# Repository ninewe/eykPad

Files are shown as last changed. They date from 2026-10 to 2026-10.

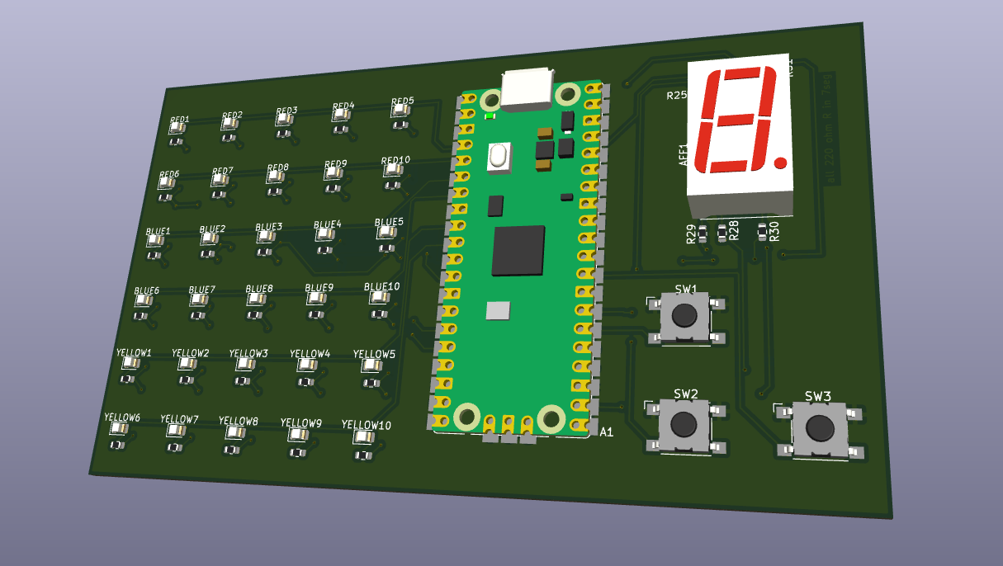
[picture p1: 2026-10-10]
board/3D view PCB.png

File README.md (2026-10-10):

# eykPad

Screenshot 2026-10-10 at 11 19 01 AM
<br><br>
<b>A multifunctional device. You can use it for:
<br><br>
   - A Timer. (Binary Mode/Regular Mode/Pomodoro Mode)<br>
   - Sequence Memorizer. (Basically Simon Says)<br>
   - Pattern Memorizer. (Memorize the pattern on the lights that show up for a split second)<br>
   - Flash Anzan. (Sequence of numbers will appear in a split second, add them up)<br>
   - Interactive Dice (Generates a Random Number.)</b>
<br><br>

For now, these are the five main functions I will focus on. 

<br>

My project mainly consists of 30 LEDS, a single-digit 7 Segment Display, and three switches. The main function for each switches are: Move right, OK, change color/boundary.

<br>

The LEDs are in a 5 by 6 matrix. I am multiplexing to save the GPIO pins. 
<br>
The top 2 rows are RED LEDs, the middle two rows are BLUE LEDs, and the last two rows are YELLOW LEDs. Since there are 10 of them each, it's easier and more efficient, since you can display numbers in base ten.

<br>

Image of the PCB in the PCB editor:<br>
Screenshot 2026-10-10 at 11 33 52 AM
<br><br>
Image of the SCHEMATIC in the SCH editor:<br>
Screenshot 2026-10-10 at 11 34 17 AM

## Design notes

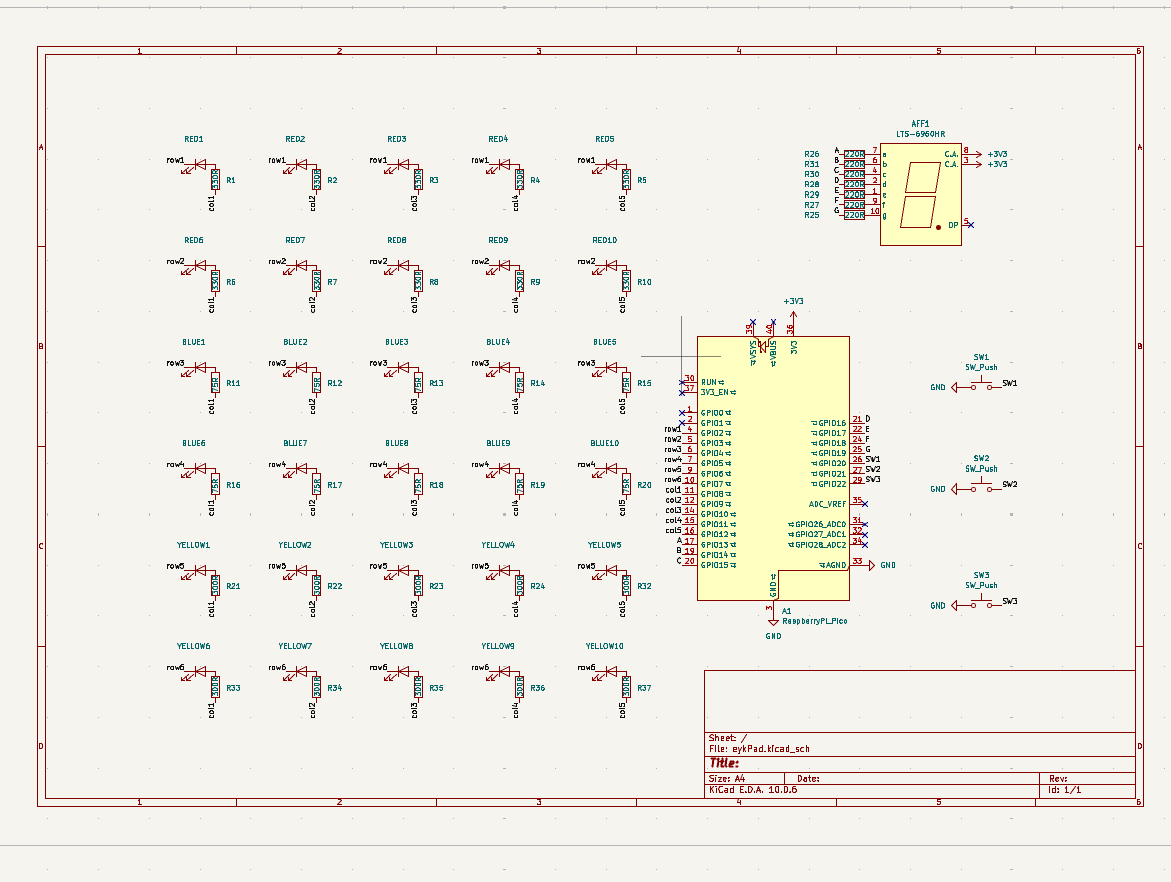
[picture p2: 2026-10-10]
board/SCHEMATIC view.png

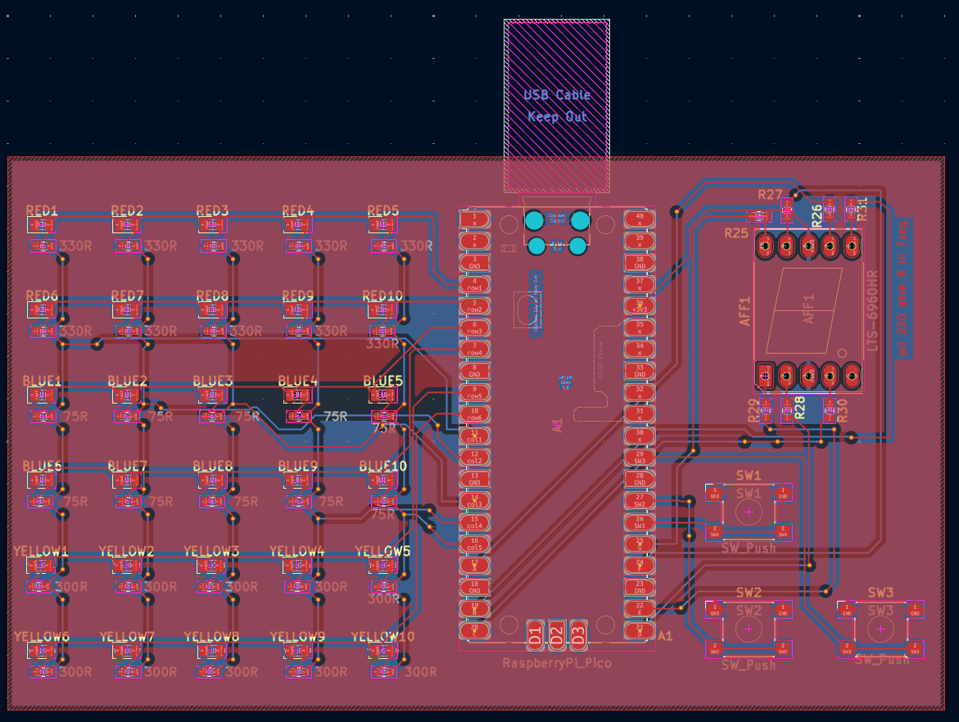
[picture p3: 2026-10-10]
board/2D view PCB.png

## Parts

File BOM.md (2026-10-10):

# eykPad – bill of materials

<!-- Generated by Half Life from project cmuusft6c0a0y01smofse3m5k. Edits here are overwritten on the next sync. -->
<!-- Generated: 2026-10-10T18:15:41.818Z -->

> [!NOTE]
> This parts list is mirrored from [Half Life](https://halflife.hackclub.com). Editing it here will not change the platform's copy, and the next sync overwrites this file.

| Week | Tier | Parts funding |
| --- | --- | --- |
| Week 1 | Tier 1 | $30.00 |

| Part | What it's for | Qty | Unit | Total | Vendor |
| --- | --- | --- | --- | --- | --- |
| [150080RS75000](https://www.digikey.com/en/products/detail/w-rth-elektronik/150080RS75000/4489918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) | Outputs of this project. (Red LED) | 12 | $0.19 | $2.28 | [DigiKey](https://www.digikey.com/en/products/detail/w-rth-elektronik/150080RS75000/4489918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) |
| [150080BS75000](https://www.digikey.com/en/products/detail/würth-elektronik/150080BS75000/4489912?s=N4IgTCBcDaIIwFYAMSAcSBCBlA7MlIAugL5A) | Outputs of this project. (Blue LED) | 12 | $0.19 | $2.28 | [DigiKey](https://www.digikey.com/en/products/detail/würth-elektronik/150080BS75000/4489912?s=N4IgTCBcDaIIwFYAMSAcSBCBlA7MlIAugL5A) |
| [150080YS75000](https://www.digikey.com/en/products/detail/würth-elektronik/150080YS75000/4489927?s=N4IgTCBcDaIIwFYAMSAcSCaBlA7MlIAugL5A) | Outputs of this project. (Yellow LED) | 12 | $0.19 | $2.28 | [DigiKey](https://www.digikey.com/en/products/detail/würth-elektronik/150080YS75000/4489927?s=N4IgTCBcDaIIwFYAMSAcSCaBlA7MlIAugL5A) |
| [SC0915](https://www.digikey.com/en/products/detail/raspberry-pi/SC0915/13624793) | The microcontroller. (Raspberry Pi Pico) | 1 | $4.59 | $4.59 | [DigiKey](https://www.digikey.com/en/products/detail/raspberry-pi/SC0915/13624793) |
| [B3FS-1000P](https://www.digikey.com/en/products/detail/aratas-formerly-omron-components/B3FS-1000P/277812) | Inputs of this project. (The buttons) | 3 | $0.75 | $2.25 | [DigiKey](https://www.digikey.com/en/products/detail/aratas-formerly-omron-components/B3FS-1000P/277812) |
| [RC0603FR-10330RL](https://www.digikey.com/en/products/detail/yageo/rc0603fr-10330rl/13694144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) | Resistors for this LED. (for RED, 330 OHMS) | 10 | $0.03 | $0.30 | [DigiKey](https://www.digikey.com/en/products/detail/yageo/rc0603fr-10330rl/13694144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) |
| [LTS-6960HR](https://www.digikey.com/en/products/detail/liteon/LTS-6960HR/3199487) | Outputs of this project. (7 segment display) | 1 | $1.82 | $1.82 | [DigiKey](https://www.digikey.com/en/products/detail/liteon/LTS-6960HR/3199487) |
| [RC0603FR-10300RL](https://www.digikey.com/en/products/detail/yageo/RC0603FR-10300RL/14008461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) | Resistors for this LED. (for YELLOW, 300 OHMS) | 10 | $0.03 | $0.30 | [DigiKey](https://www.digikey.com/en/products/detail/yageo/RC0603FR-10300RL/14008461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) |
| [RC0603FR-0775RL](https://www.digikey.com/en/products/detail/yageo/RC0603FR-0775RL/727377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) | Resistors for this LED. (for BLUE, 75 OHMS) | 10 | $0.03 | $0.30 | [DigiKey](https://www.digikey.com/en/products/detail/yageo/RC0603FR-0775RL/727377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) |
| **Parts subtotal** | — | — | — | **$16.40** | — |
| **Tax & shipping** | — | — | — | **$7.75** | — |
| **Total** | — | — | — | **$24.15** | — |

$5.85 left of the tier's funding.

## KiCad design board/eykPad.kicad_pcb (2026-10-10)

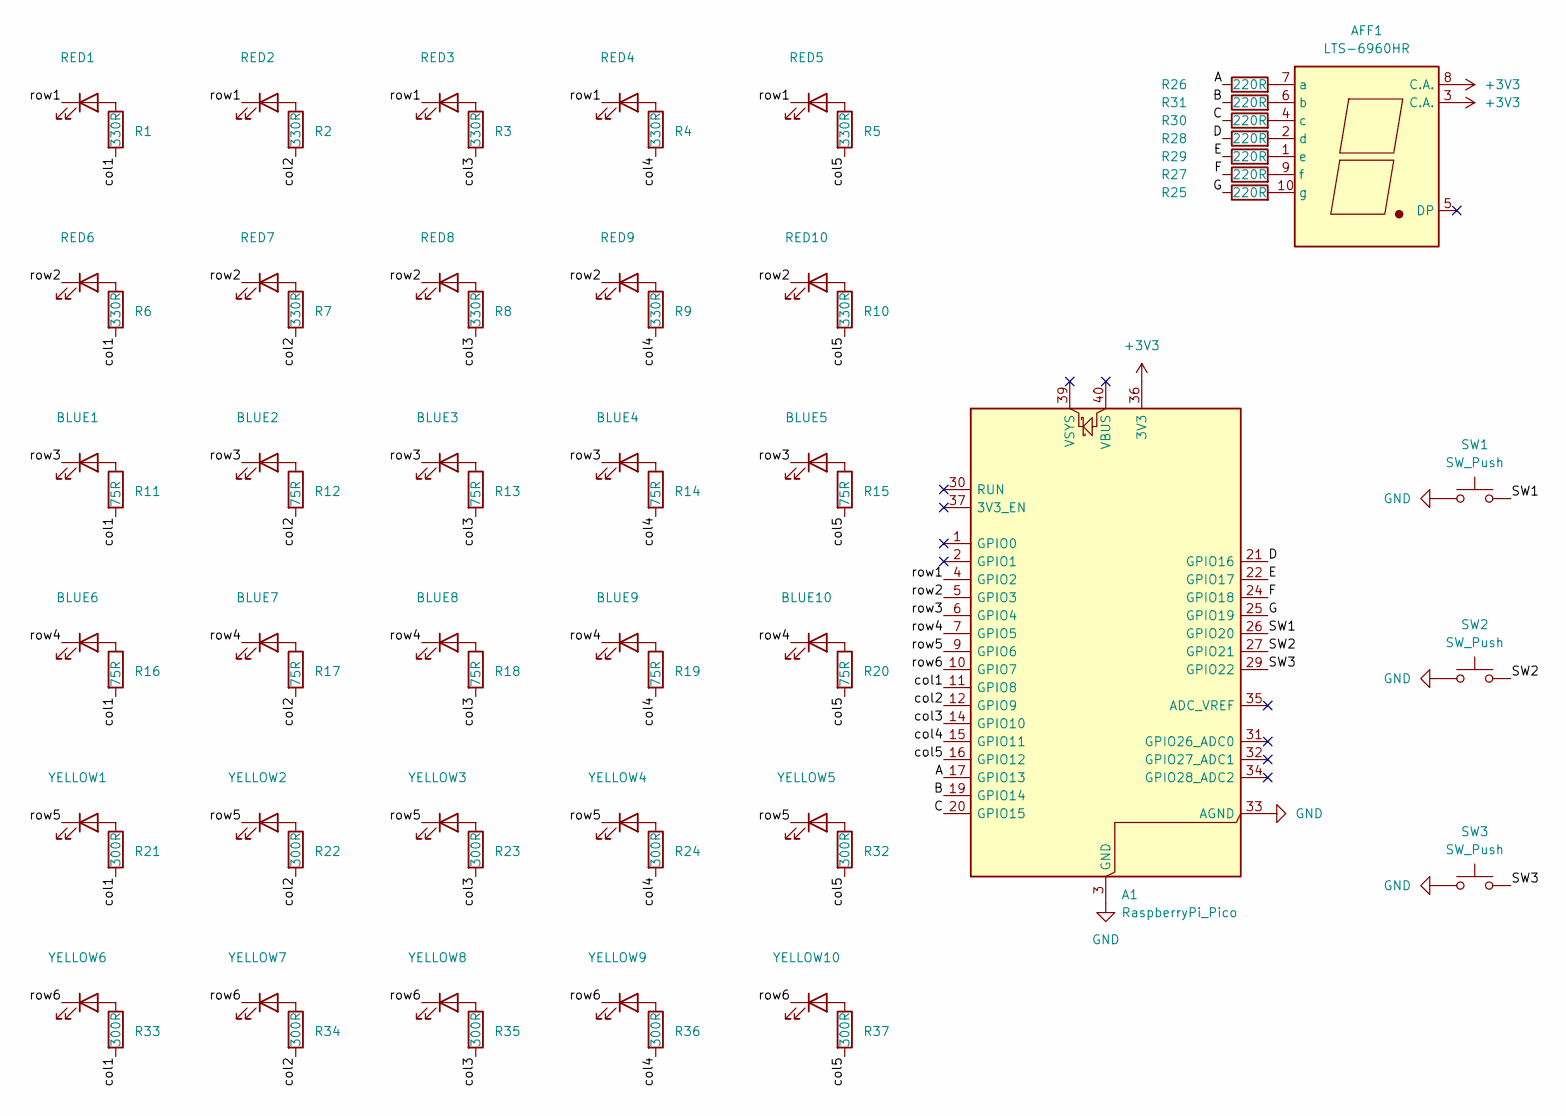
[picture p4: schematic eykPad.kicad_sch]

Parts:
A1: RaspberryPi_Pico; RaspberryPi_Pico_SMD_HandSolder
AFF1: LTS-6960HR; 7SegmentLED_LTS6760_LTS6780
BLUE1, BLUE2, BLUE3, BLUE4, BLUE5, BLUE6, BLUE7, BLUE8, BLUE9, BLUE10: 150080BS75000; LED_0805_2012Metric
R1, R2, R3, R4, R5, R6, R7, R8, R9, R10: 330R; R_0603_1608Metric
R11, R12, R13, R14, R15, R16, R17, R18, R19, R20: 75R; R_0603_1608Metric
R21, R22, R23, R24, R32, R33, R34, R35, R36, R37: 300R; R_0603_1608Metric
R25, R26, R27, R28, R29, R30, R31: 220R; R_0603_1608Metric
RED1, RED2, RED3, RED4, RED5, RED6, RED7, RED8, RED9, RED10: 150080RS75000; LED_0805_2012Metric
SW1, SW2, SW3: SW_Push; SW_SPST_Omron_B3FS-100xP
YELLOW1, YELLOW2, YELLOW3, YELLOW4, YELLOW5, YELLOW6, YELLOW7, YELLOW8, YELLOW9, YELLOW10: 150080YS75000; LED_0805_2012Metric

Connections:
+3V3: A1.36 (3V3), AFF1.3 (C.A.), AFF1.8 (C.A.)
/A: A1.17 (GPIO13), R26.1
/B: A1.19 (GPIO14), R31.1
/C: A1.20 (GPIO15), R30.1
/D: A1.21 (GPIO16), R28.1
/E: A1.22 (GPIO17), R29.1
/F: A1.24 (GPIO18), R27.1
/G: A1.25 (GPIO19), R25.1
/SW1: A1.26 (GPIO20), SW1.2
/SW2: A1.27 (GPIO21), SW2.2
/SW3: A1.29 (GPIO22), SW3.2
/col1: A1.11 (GPIO8), R1.2, R6.2, R11.2, R16.2, R21.2, R33.2
/col2: A1.12 (GPIO9), R2.2, R7.2, R12.2, R17.2, R22.2, R34.2
/col3: A1.14 (GPIO10), R3.2, R8.2, R13.2, R18.2, R23.2, R35.2
/col4: A1.15 (GPIO11), R4.2, R9.2, R14.2, R19.2, R24.2, R36.2
/col5: A1.16 (GPIO12), R5.2, R10.2, R15.2, R20.2, R32.2, R37.2
/row1: A1.4 (GPIO2), RED1.1 (K), RED2.1 (K), RED3.1 (K), RED4.1 (K), RED5.1 (K)
/row2: A1.5 (GPIO3), RED6.1 (K), RED7.1 (K), RED8.1 (K), RED9.1 (K), RED10.1 (K)
/row3: A1.6 (GPIO4), BLUE1.1 (K), BLUE2.1 (K), BLUE3.1 (K), BLUE4.1 (K), BLUE5.1 (K)
/row4: A1.7 (GPIO5), BLUE6.1 (K), BLUE7.1 (K), BLUE8.1 (K), BLUE9.1 (K), BLUE10.1 (K)
/row5: A1.9 (GPIO6), YELLOW1.1 (K), YELLOW2.1 (K), YELLOW3.1 (K), YELLOW4.1 (K), YELLOW5.1 (K)
/row6: A1.10 (GPIO7), YELLOW6.1 (K), YELLOW7.1 (K), YELLOW8.1 (K), YELLOW9.1 (K), YELLOW10.1 (K)
GND: A1.3 (GND), A1.8 (GND), A1.13 (GND), A1.18 (GND), A1.23 (GND), A1.28 (GND), A1.33 (AGND), A1.38 (GND), SW1.1, SW2.1, SW3.1
unnamed: AFF1.7 (a), R26.2
unnamed: AFF1.6 (b), R31.2
unnamed: AFF1.4 (c), R30.2
unnamed: AFF1.2 (d), R28.2
unnamed: AFF1.1 (e), R29.2
unnamed: AFF1.9 (f), R27.2
unnamed: AFF1.10 (g), R25.2
unnamed: BLUE1.2 (A), R11.1
unnamed: BLUE2.2 (A), R12.1
unnamed: BLUE3.2 (A), R13.1
unnamed: BLUE4.2 (A), R14.1
unnamed: BLUE5.2 (A), R15.1
unnamed: BLUE6.2 (A), R16.1
unnamed: BLUE7.2 (A), R17.1
unnamed: BLUE8.2 (A), R18.1
unnamed: BLUE9.2 (A), R19.1
unnamed: BLUE10.2 (A), R20.1
unnamed: R1.1, RED1.2 (A)
unnamed: R2.1, RED2.2 (A)
unnamed: R3.1, RED3.2 (A)
unnamed: R4.1, RED4.2 (A)
unnamed: R5.1, RED5.2 (A)
unnamed: R6.1, RED6.2 (A)
unnamed: R7.1, RED7.2 (A)
unnamed: R8.1, RED8.2 (A)
unnamed: R9.1, RED9.2 (A)
unnamed: R10.1, RED10.2 (A)
unnamed: R21.1, YELLOW1.2 (A)
unnamed: R22.1, YELLOW2.2 (A)
unnamed: R23.1, YELLOW3.2 (A)
unnamed: R24.1, YELLOW4.2 (A)
unnamed: R32.1, YELLOW5.2 (A)
unnamed: R33.1, YELLOW6.2 (A)
unnamed: R34.1, YELLOW7.2 (A)
unnamed: R35.1, YELLOW8.2 (A)
unnamed: R36.1, YELLOW9.2 (A)
unnamed: R37.1, YELLOW10.2 (A)

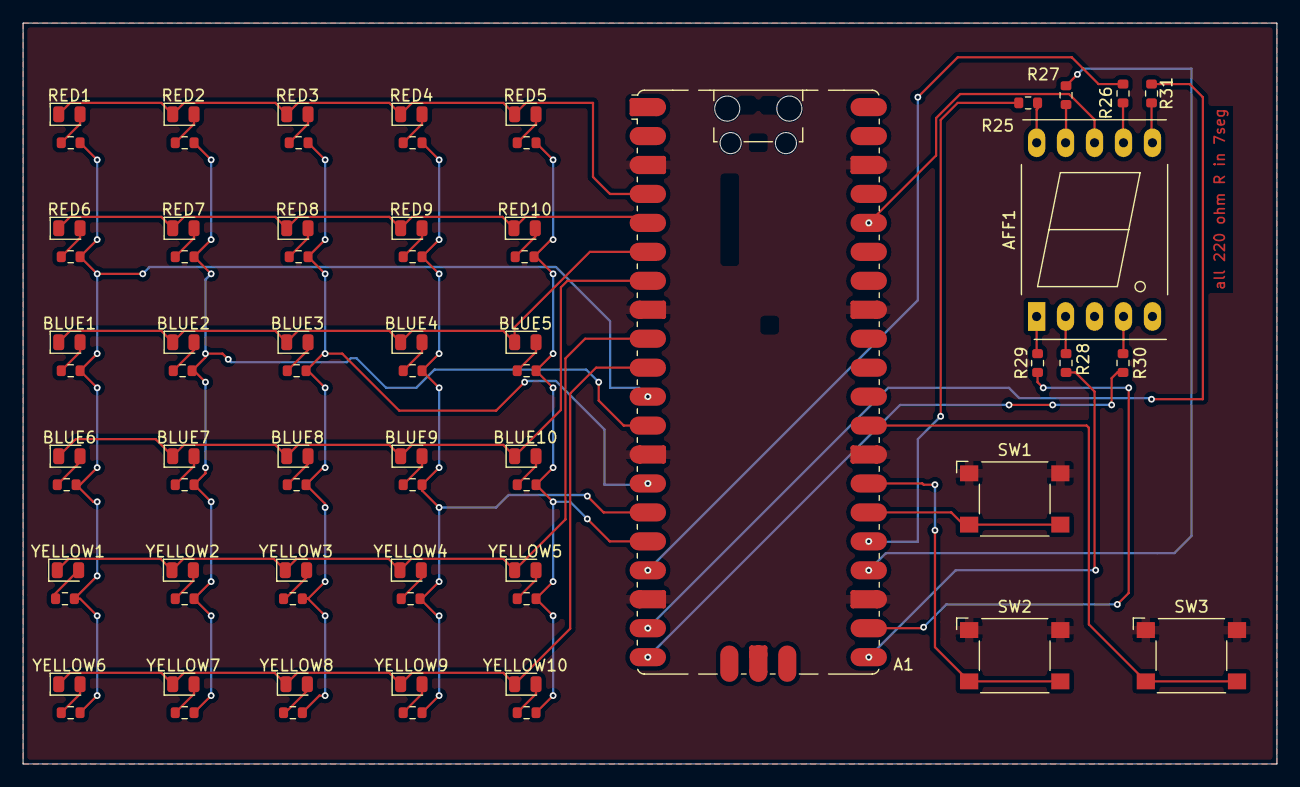
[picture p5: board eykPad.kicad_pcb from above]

Board: 2 copper layers, 110.0 x 65.0 mm, 72 parts (0 on the bottom side), 60 nets.

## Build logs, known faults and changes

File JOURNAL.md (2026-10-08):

# eykPad – devlog

<!-- Generated by Half Life from project cmuusft6c0a0y01smofse3m5k. Edits here are overwritten on the next sync. -->
<!-- Generated: 2026-10-08T02:33:54.476Z -->

> [!NOTE]
> This devlog is mirrored from [Half Life](https://halflife.hackclub.com). Editing it here will not change the platform's copy, and the next sync overwrites this file.

> A simple PCB with lights, buttons, and you can play fun games!

| Week | Tier | Hours logged | Entries |
| --- | --- | --- | --- |
| Week 1 | Tier 1 | 5.36h | 3 |

## Contents

1. [2026-10-05 – PNG image](#2026-10-05-png-imagehttpshalflifehackclub-assetscomhackclub-)
2. [2026-10-06 – ![Screenshot 2026-10-06 at 8.31.12 PM](https://halflife.hackclub-assets.com/hackclub-half-life/sessions/WKHlWTArmY0mZYT5WZnx8k27wposj8rz/289f8daa0ad5850755dfff0e2e3b12ea6d21d6dfb6c68149330e585fa36e397](#2026-10-06-screenshot-2026-10-06-at-83112-pmhttpshalflifehac)
3. [2026-10-07 – Pretty much nothing to say here except that I found an alternative 7 segment display (it's way cheaper, by 6 whole dollars) so I decided to wire that instead. It's a through hole display, but I will c](#2026-10-07-pretty-much-nothing-to-say-here-except-that-i-fou)

## Design

### 2026-10-05 – PNG image

**2.33h**

PNG image

I finished the PCB and the Schematic! Basically, this pad has 24 LED, and I use multiplexing to save GPIO pins. It also has a seven segment display and a few buttons so it can be interactive!

The microcontroller is a Raspberry Pi Pico 1.

Schematic:

PNG image

(I will add fifteen  minutes, which is spent on footprint/parts research. Rest is lapse videos.)

[Timelapse](https://lookout.hackclub.com/api/media/ab7d1ac2-cdb3-45bd-84aa-08826cc5ecb7/video.mp4)

[Timelapse](https://lookout.hackclub.com/api/media/36cd0763-2adf-4fdf-bcc2-7ee5959872a2/video.mp4)

### 2026-10-06 – ![Screenshot 2026-10-06 at 8.31.12 PM](https://halflife.hackclub-assets.com/hackclub-half-life/sessions/WKHlWTArmY0mZYT5WZnx8k27wposj8rz/289f8daa0ad5850755dfff0e2e3b12ea6d21d6dfb6c68149330e585fa36e397

**1.83h**

Screenshot 2026-10-06 at 8.31.12 PM

**I finished the updated new PCB!**

I changed the amount of lights from 24 LED (4 by 6 matrix) to 30 LED (5 by 6 matrix) with 3 different colors, RED, BLUE, and YELLOW, 10 LED each. This is because it's going to be easier and more efficient especially when you display numbers. The RED can stand for the hundreds digit, BLUE ten, and YELLOW first.

What really was hard though was routing and where to put all parts. Eventually, I put the microcontroller in the middle and all the LED connect to it. (don't worry if the microcontroller is a bit too low for the USB to reach, I will make sure that the case won't interfere with it)

(30 minutes spent on extra research on parts. This was really hard because I needed lights and other parts with the exact same footprint, and check for other details that  would  interfere with my project. I also needed for it to be as cheap as possible. I also had to double check if everything will function and work, and I have to be extra careful since this is my first time.)

[Timelapse](https://lookout.hackclub.com/api/media/40d374ec-3b0b-4ef7-a879-84daaf5b4fb0/video.mp4)

[Timelapse](https://lookout.hackclub.com/api/media/f53070ea-f378-4213-928d-8e304a068122/video.mp4)

[Timelapse](https://lookout.hackclub.com/api/media/a2d40b95-6172-47c2-8c5e-61fc3a2bea91/video.mp4)

### 2026-10-07 – Pretty much nothing to say here except that I found an alternative 7 segment display (it's way cheaper, by 6 whole dollars) so I decided to wire that instead. It's a through hole display, but I will c

**1.2h**

Pretty much nothing to say here except that I found an alternative 7 segment display (it's way cheaper, by 6 whole dollars) so I decided to wire that instead. It's a through hole display, but I will cut the unnecessary ends off when I'm building to keep the bottom of the PCB flat.
I think this PCB looks fine. And I also changed the unconnected GPIO PIN numbers to 0 and 1 because that's like testing serial communication in some microcontrollers (I think) and I think it does not apply to Raspberry Pi Pico but I changed it to that anyways. Rerouted parts of the PCB, didn't take too long.
I also updated the resistor values.

**It took me about 15 minutes to do the math and research. Since I was really new to multiplexing, this was especially a hard challenge.**

Now its like this:
RED LED- 330 ohm
YELLOW LED- 300 ohm
BLUE LED- 75 ohm

each light has its own resistor, so 30 resistors total (for LED)
multiplexing (5 x 6)

Screenshot 2026-10-07 at 7.31.08 PM

Screenshot 2026-10-07 at 7.31.13 PM

[Timelapse](https://lookout.hackclub.com/api/media/11f002b7-1f3d-4a3b-9f83-903b72ebfe16/video.mp4)

[Timelapse](https://lookout.hackclub.com/api/media/9f146cb9-b0cb-49af-a1aa-0366a3275fb5/video.mp4)

[Timelapse](https://lookout.hackclub.com/api/media/2a35cfd3-2edd-4e18-be65-0beee193f7c4/video.mp4)

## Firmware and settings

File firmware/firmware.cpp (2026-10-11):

#include "pico/stdlib.h"
#include <stdint.h>

constexpr uint8_t ROWS = 6;
constexpr uint8_t COLS = 5;
constexpr uint8_t BUTTONS = 3;
const uint8_t rowPins[ROWS] = {2, 3, 4, 5, 6, 7};
const uint8_t colPins[COLS] = {8, 9, 10, 11, 12};
const uint8_t segmentPins[7] = {13, 14, 15, 16, 17, 18, 19};
const uint8_t buttonPins[BUTTONS] = {20, 21, 22};
constexpr bool ROW_ON  = true;
constexpr bool ROW_OFF = false;
constexpr bool COL_ON  = false;
constexpr bool COL_OFF = true;
constexpr uint32_t DEBOUNCE_MS = 25;
constexpr uint32_t LONG_PRESS_MS = 800;
constexpr uint32_t MATRIX_CELL_US = 200;
constexpr uint32_t RESULT_MS = 1200;

enum Mode : uint8_t {
    IDLE_MODE = 0,
    TIMER_MODE = 1,
    SEQUENCE_MODE = 2
};

Mode currentMode = IDLE_MODE;
bool inMenu = false;
uint8_t menuChoice = IDLE_MODE;
uint32_t randomState = 0xA341316Cu;

uint32_t random32() {
    randomState ^= randomState << 13;
    randomState ^= randomState >> 17;
    randomState ^= randomState << 5;
    return randomState;
}

uint8_t randomBetween(uint8_t limit) {
    return limit ? static_cast<uint8_t>(random32() % limit) : 0;
}

uint64_t nowMs() {
    return time_us_64() / 1000u;
}

struct Button {
    bool lastRaw = true;
    bool stable = true;
    bool shortPress = false;
    bool longPress = false;
    bool longHandled = false;
    uint64_t changedAt = 0;
    uint64_t pressedAt = 0;
};

Button buttons[BUTTONS];

void updateButtons(uint64_t now) {
    for (uint8_t i = 0; i < BUTTONS; ++i) {
        Button &b = buttons[i];
        b.shortPress = false;
        b.longPress = false;
        bool reading = gpio_get(buttonPins[i]);
        if (reading != b.lastRaw) {
            b.lastRaw = reading;
            b.changedAt = now;
        }
        if ((now - b.changedAt) >= DEBOUNCE_MS && reading != b.stable) {
            b.stable = reading;
            if (!b.stable) {
                b.pressedAt = now;
                b.longHandled = false;
            } else if (!b.longHandled) {
                b.shortPress = true;
            }
        }
        if (!b.stable &&
            !b.longHandled &&
            (now - b.pressedAt) >= LONG_PRESS_MS) {
            b.longPress = true;
            b.longHandled = true;
        }
    }
}

//7 segment

const uint8_t digitSegments[10] = {
    0b0111111, // 0
    0b0000110, // 1
    0b1011011, // 2
    0b1001111, // 3
    0b1100110, // 4
    0b1101101, // 5
    0b1111101, // 6
    0b0000111, // 7
    0b1111111, // 8
    0b1101111  // 9
};

void showDigit(int8_t digit) {
    for (uint8_t s = 0; s < 7; ++s) {
        bool on = digit >= 0 &&
                  digit <= 9 &&
                  ((digitSegments[digit] >> s) & 1u);
        gpio_put(segmentPins[s], on ? false : true);
    }
}

bool matrixCellOn(uint8_t row, uint8_t col);
uint8_t matrixIndex = 0;
uint64_t lastMatrixScanUs = 0;

void scanOneMatrixCell() {
    for (uint8_t r = 0; r < ROWS; ++r) {
        gpio_put(rowPins[r], ROW_OFF);
    }
    for (uint8_t c = 0; c < COLS; ++c) {
        gpio_put(colPins[c], COL_OFF);
    }
    uint8_t row = matrixIndex / COLS;
    uint8_t col = matrixIndex % COLS;
    if (matrixCellOn(row, col)) {
        gpio_put(colPins[col], COL_ON);
        gpio_put(rowPins[row], ROW_ON);
    }
    matrixIndex = (matrixIndex + 1u) % (ROWS * COLS);
}

uint8_t timerPresetMinutes = 5;
bool timerRunning = false;
uint32_t timerRemainingMs = 5u * 60u * 1000u;
uint64_t timerLastUpdate = 0;

uint32_t timerDurationMs() {
    return static_cast<uint32_t>(timerPresetMinutes) * 60u * 1000u;
}

void resetTimer(uint64_t now) {
    timerRunning = false;
    timerRemainingMs = timerDurationMs();
    timerLastUpdate = now;
}

void updateTimer(uint64_t now) {
    if (!timerRunning) {
        timerLastUpdate = now;
        return;
    }
    uint64_t elapsed = now - timerLastUpdate;
    timerLastUpdate = now;
    if (elapsed >= timerRemainingMs) {
        timerRemainingMs = 0;
        timerRunning = false;
    } else {
        timerRemainingMs -= static_cast<uint32_t>(elapsed);
    }
}

uint8_t timerRemainingMinutes() {
    return static_cast<uint8_t>((timerRemainingMs + 59999u) / 60000u);
}

//memory game

enum SimonPhase : uint8_t {
    SIMON_PLAYBACK,
    SIMON_INPUT,
    SIMON_RESULT
};

SimonPhase simonPhase = SIMON_PLAYBACK;
uint8_t simonSequence[9] = {};
uint8_t simonLevel = 1;
uint8_t simonPlayIndex = 0;
uint8_t simonInputIndex = 0;
uint8_t simonSelectedSection = 0;
bool simonLit = false;
bool simonWon = false;
uint64_t simonNextAt = 0;

void beginSimonPlayback(uint64_t now) {
    simonPhase = SIMON_PLAYBACK;
    simonPlayIndex = 0;
    simonInputIndex = 0;
    simonLit = false;
    simonNextAt = now;
}

void startSimon(uint64_t now) {
    for (uint8_t i = 0; i < 9; ++i) {
        simonSequence[i] = randomBetween(3);
    }
    simonLevel = 1;
    simonSelectedSection = 0;
    beginSimonPlayback(now);
}

void updateSimon(uint64_t now) {
    if (simonPhase != SIMON_PLAYBACK || now < simonNextAt) {
        return;
    }
    if (!simonLit) {
        if (simonPlayIndex >= simonLevel) {
            simonPhase = SIMON_INPUT;
            simonInputIndex = 0;
            simonSelectedSection = 0;
            return;
        }
        simonLit = true;
        simonNextAt = now + 450u;
    } else {
        simonLit = false;
        ++simonPlayIndex;
        simonNextAt = now + 180u;
    }
}

void startMode(Mode mode, uint64_t now) {
    currentMode = mode;
    switch (currentMode) {
        case IDLE_MODE:
            break;
        case TIMER_MODE:
            timerPresetMinutes = 5;
            resetTimer(now);
            break;
        case SEQUENCE_MODE:
            startSimon(now);
            break;
    }
}

void updateCurrentMode(uint64_t now) {
    switch (currentMode) {
        case IDLE_MODE:
            break;
        case TIMER_MODE:
            updateTimer(now);
            break;
        case SEQUENCE_MODE:
            updateSimon(now);
            if (simonPhase == SIMON_RESULT && now >= simonNextAt) {
                if (simonWon && simonLevel < 9) {
                    ++simonLevel;
                    beginSimonPlayback(now);
                } else {
                    startSimon(now);
                }
            }
            break;
    }
}

//buttons

void handleModeButtons(uint64_t now) {
    const bool sw1 = buttons[0].shortPress;
    const bool sw2 = buttons[1].shortPress;
    const bool sw3 = buttons[2].shortPress;
    const bool sw3Long = buttons[2].longPress;
    switch (currentMode) {
        case IDLE_MODE:
            break;
        case TIMER_MODE:
            if (!timerRunning && sw1) {
                timerPresetMinutes = (timerPresetMinutes >= 9)
                    ? 1 : static_cast<uint8_t>(timerPresetMinutes + 1u);
                resetTimer(now);
            }
            if (!timerRunning && sw2) {
                timerPresetMinutes = (timerPresetMinutes <= 1)
                    ? 9 : static_cast<uint8_t>(timerPresetMinutes - 1u);
                resetTimer(now);
            }
            if (sw3Long) {
                resetTimer(now);
            } else if (sw3) {
                if (timerRemainingMs == 0) {
                    resetTimer(now);
                }
                timerRunning = !timerRunning;
                timerLastUpdate = now;
            }
            break;
        case SEQUENCE_MODE:
            if (simonPhase == SIMON_INPUT) {
                if (sw1) {
                    simonSelectedSection =
                        static_cast<uint8_t>((simonSelectedSection + 1u) % 3u);
                }
                if (sw2) {
                    beginSimonPlayback(now);
                }
                if (sw3 && simonPhase == SIMON_INPUT) {
                    if (simonSelectedSection != simonSequence[simonInputIndex]) {
                        simonWon = false;
                        simonPhase = SIMON_RESULT;
                        simonNextAt = now + RESULT_MS;
                    } else {
                        ++simonInputIndex;
                        if (simonInputIndex >= simonLevel) {
                            simonWon = true;
                            simonPhase = SIMON_RESULT;
                            simonNextAt = now + RESULT_MS;
                        }
                    }
                }
            }
            break;
    }
}

//render matrix

bool sectionCell(uint8_t row, uint8_t section) {
    return row / 2u == section;
}

bool matrixCellOn(uint8_t row, uint8_t col) {
    switch (currentMode) {
        case IDLE_MODE:
            return false;
        case TIMER_MODE: {
            uint32_t total = timerDurationMs();
            if (total == 0) {
                return false;
            }
            uint32_t litCount = (timerRemainingMs * 30u) / total;
            uint8_t index = static_cast<uint8_t>(row * COLS + col);
            return index < litCount;
        }
        case SEQUENCE_MODE:
            if (simonPhase == SIMON_PLAYBACK && simonLit) {
                return sectionCell(row, simonSequence[simonPlayIndex]);
            }
            if (simonPhase == SIMON_INPUT) {
                return sectionCell(row, simonSelectedSection);
            }
            if (simonPhase == SIMON_RESULT && simonWon) {
                return true;
            }
            return false;
    }
    return false;
}

int8_t digitToShow(uint64_t now) {
    if (inMenu) {
        return ((now / 500u) % 2u == 0)
            ? static_cast<int8_t>(menuChoice) : -1;
    }
    switch (currentMode) {
        case IDLE_MODE:
            return 0;
        case TIMER_MODE:
            return static_cast<int8_t>(timerRemainingMinutes());
        case SEQUENCE_MODE:
            if (simonPhase == SIMON_RESULT) {
                return simonWon ? 1 : 0;
            }
            return static_cast<int8_t>(simonLevel);
    }
    return -1;
}

void updateSevenSegment(uint64_t now) {
    showDigit(digitToShow(now));
}

int main() {
    stdio_init_all();
    for (uint8_t r = 0; r < ROWS; ++r) {
        gpio_init(rowPins[r]);
        gpio_set_dir(rowPins[r], GPIO_OUT);
        gpio_put(rowPins[r], ROW_OFF);
    }
    for (uint8_t c = 0; c < COLS; ++c) {
        gpio_init(colPins[c]);
        gpio_set_dir(colPins[c], GPIO_OUT);
        gpio_put(colPins[c], COL_OFF);
    }
    for (uint8_t s = 0; s < 7; ++s) {
        gpio_init(segmentPins[s]);
        gpio_set_dir(segmentPins[s], GPIO_OUT);
        gpio_put(segmentPins[s], true); // common-anode segments off
    }
    for (uint8_t i = 0; i < BUTTONS; ++i) {
        gpio_init(buttonPins[i]);
        gpio_set_dir(buttonPins[i], GPIO_IN);
        gpio_pull_up(buttonPins[i]);
    }
    randomState = time_us_32() | 1u;
    uint64_t now = nowMs();
    startMode(IDLE_MODE, now);
    while (true) {
        now = nowMs();
        updateButtons(now);
        if (buttons[0].longPress) {
            inMenu = !inMenu;
            menuChoice = currentMode;
            timerLastUpdate = now;
        }
        if (inMenu) {
            if (buttons[1].shortPress) {
                menuChoice = static_cast<uint8_t>(
                    menuChoice >= SEQUENCE_MODE
                    ? static_cast<uint8_t>(IDLE_MODE)
                    : static_cast<uint8_t>(menuChoice + 1u)
                );
            }
            if (buttons[2].shortPress) {
                startMode(static_cast<Mode>(menuChoice), now);
                inMenu = false;
            }
        } else {
            handleModeButtons(now);
            updateCurrentMode(now);
        }
        updateSevenSegment(now);
        uint64_t nowUs = time_us_64();
        if (nowUs - lastMatrixScanUs >= MATRIX_CELL_US) {
            lastMatrixScanUs = nowUs;
            scanOneMatrixCell();
        }
        sleep_us(20);
    }
}

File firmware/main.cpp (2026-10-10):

#include <iostream>

int main() {
    std::cout << "Welcome to OnlineIDE Pro!" << std::endl;
    std::cout << "Start coding in C++..." << std::endl;
    int a, b;
    std::cout << "Enter a number: ";
    std::cin >> a;
    std::cout << "Enter another number: ";
    std::cin >> b;
    std::cout << "The sum of " << a << " and " << b << " is " << a + b << std::endl;
    return 0;
}
